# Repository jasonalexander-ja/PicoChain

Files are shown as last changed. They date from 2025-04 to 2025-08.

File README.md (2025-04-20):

# PicoChain

Pico(Daisy)Chain is a simple standard for creating daisy chains of connected devices, allowing I2C and power to be easily distributed out using ethernet patch cables. 

This is a repository containing documentation and reference hardware + software implementations. 

All hardware reference implementations are in KiCAD 8+ format with the PCB layout and Gerbers. 

### Contents: 

- [PicoChainReference](/PicoChainReference); A generic reference design breaking out the power and I2C to pin headers, this can be easily adapted to what ever purpose is desired. 
- [PicoChainZero](/PicoChainZero); A reference design using the Raspberry Pi Zero as a I2C controller, breaks out the Pi Zero's serial to a USB-C connector. 
- [PicoChainTerminator](/PicoChainTerminator); A reference design for a termination endpoint device, one of these needs to be present at the start and end of a chain. 

## Design Overview 

PicoChain uses differential I2C, 12 + 24 volts, all sent down a single RJ45 & twisted pair allowing communication and power for microcontrollers + motors to be supplied using commonly available ethernet patch cables. 

Generation of the differential I2C is handled by the [NXP PCA9615](https://www.nxp.com/docs/en/data-sheet/PCA9615.pdf) meaning that when SCL and SCA is hooked up to this chip, all the same I2C libraries and implementation automatically work with no further modifications. 

The 12 + 24 volts is supplied with the assumption that this will be regulated into the relevant required voltages by the connected devices, the reference implementations regulates a 5V for the microcontroller and a 5V for servo and similar small motors off of the 12V line, and a 12V line is regulated off of the 24V line intended for high power motors. 

Each PicoChain device has 2 RJ45 connectors to send and receive power and data, they don't have a particular direction are all the reference designs have the RJ45s passively connected, tapping off of power and I2C as needed, however, all PicoChain chains need terminators at either end. 

Generally, this is designed for running sequences across some connected devices, with the idea that only 1 large load (I.E. a motor) will be running at a time, reducing the current load going through the patch cables and chained devices. 

### Pinout 

| **RJ45 Pin** | **Function** |
|---|---|
| **1** | GND |
| **2** | +24V |
| **3** | DSDAM |
| **4** | DSCLM |
| **5** | DSCLP |
| **6** | DSDAP |
| **7** | GND |
| **8** | +12V |

Pins 3-6 (inclusive) are generated by the [PCA9615](https://www.nxp.com/docs/en/data-sheet/PCA9615.pdf) and are connected directly to ICs on each device.

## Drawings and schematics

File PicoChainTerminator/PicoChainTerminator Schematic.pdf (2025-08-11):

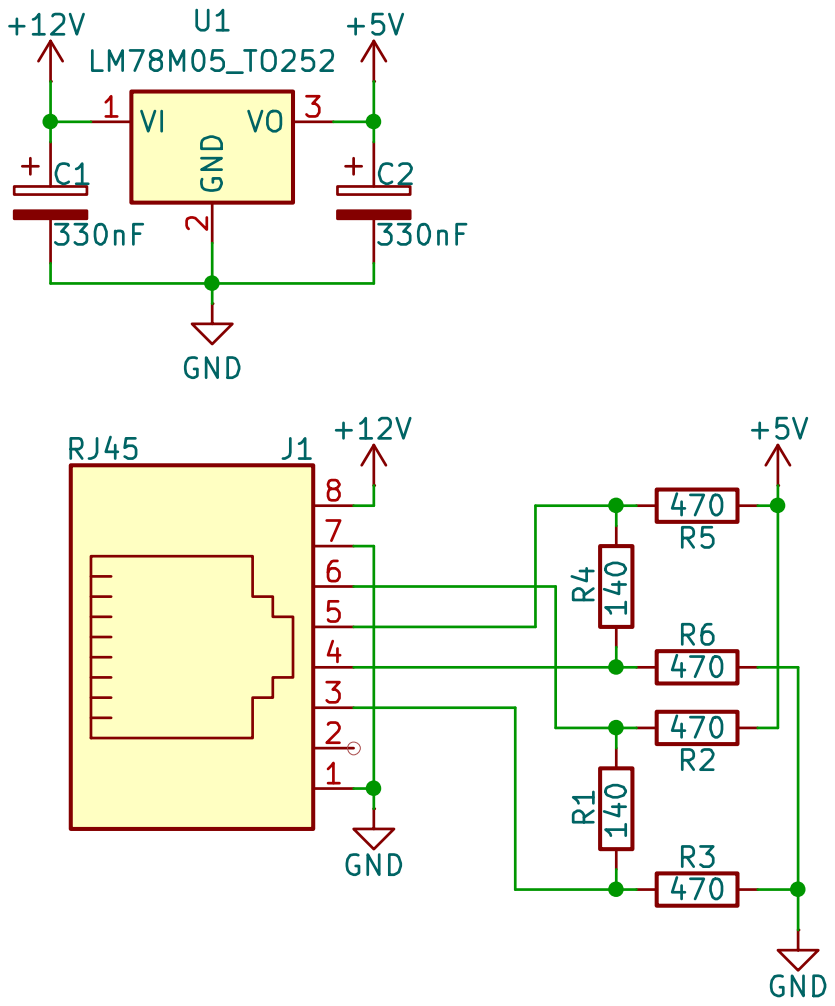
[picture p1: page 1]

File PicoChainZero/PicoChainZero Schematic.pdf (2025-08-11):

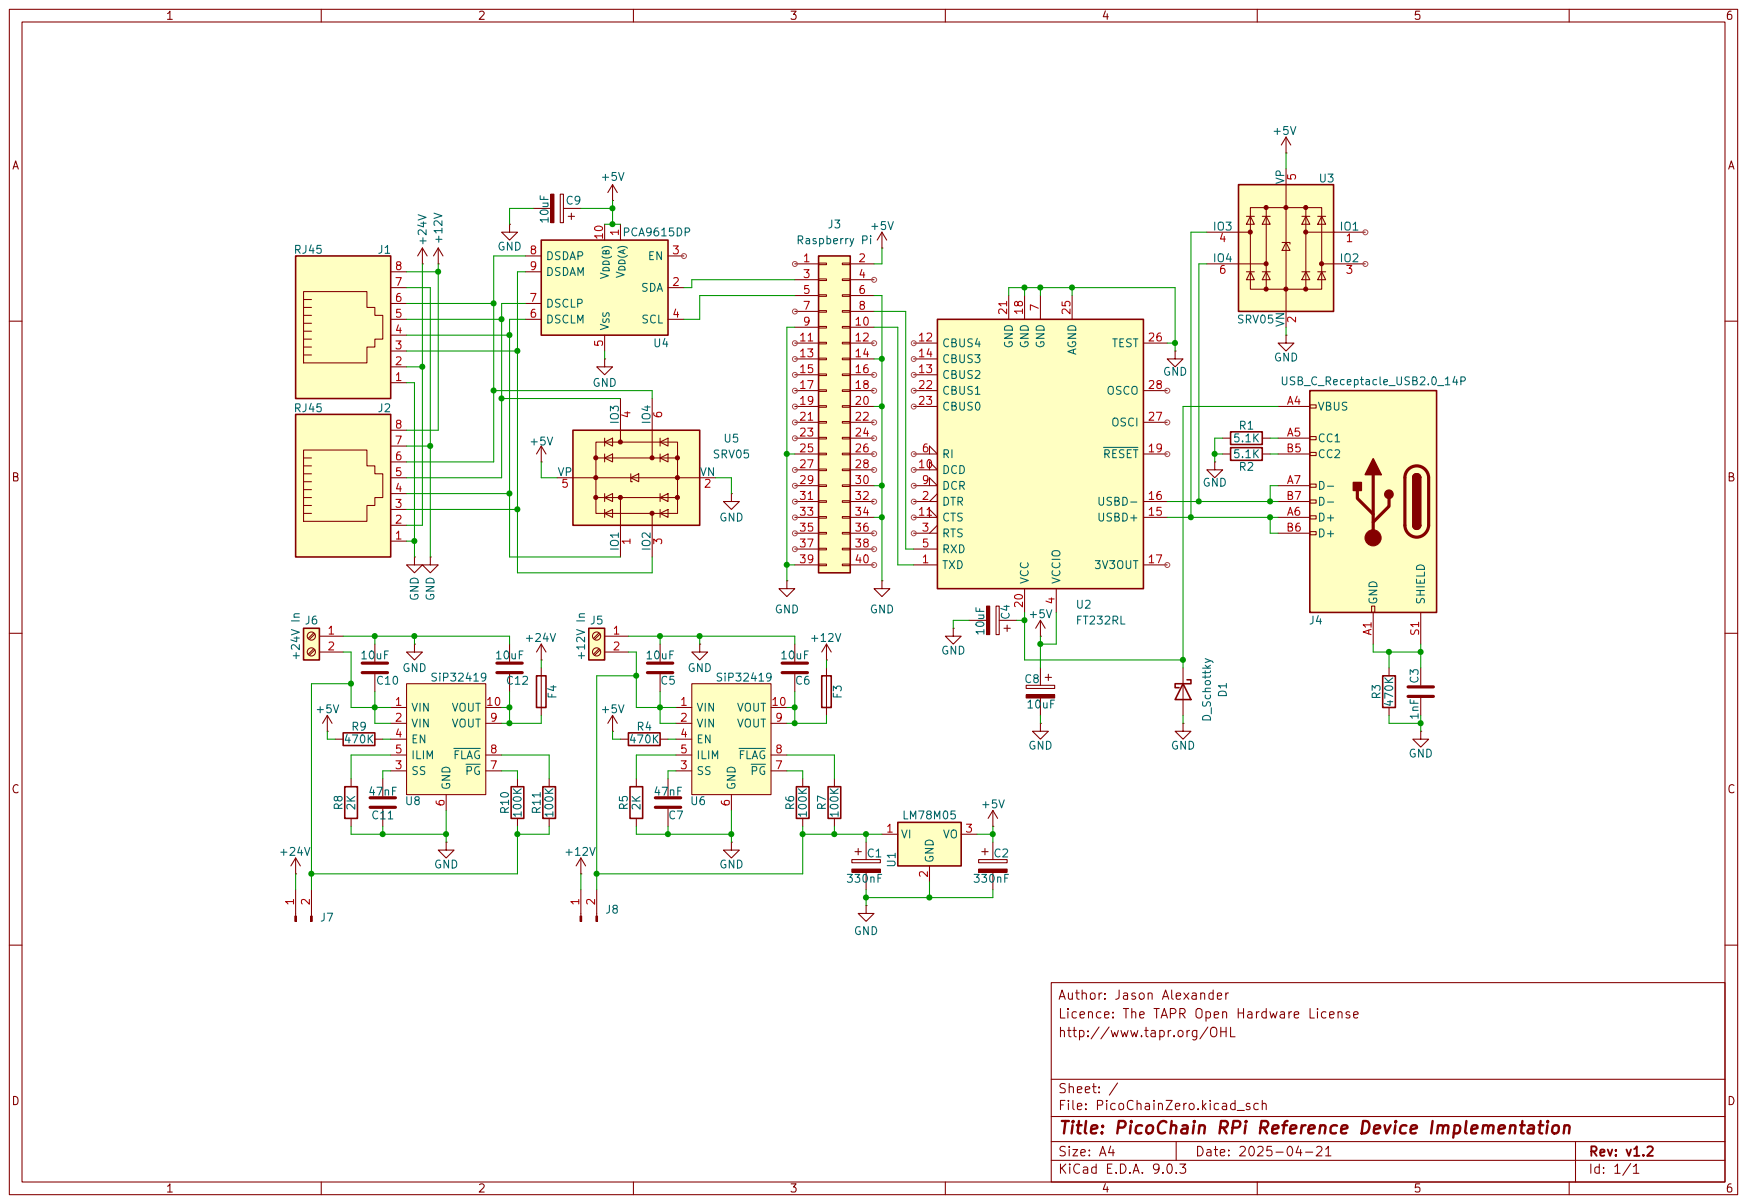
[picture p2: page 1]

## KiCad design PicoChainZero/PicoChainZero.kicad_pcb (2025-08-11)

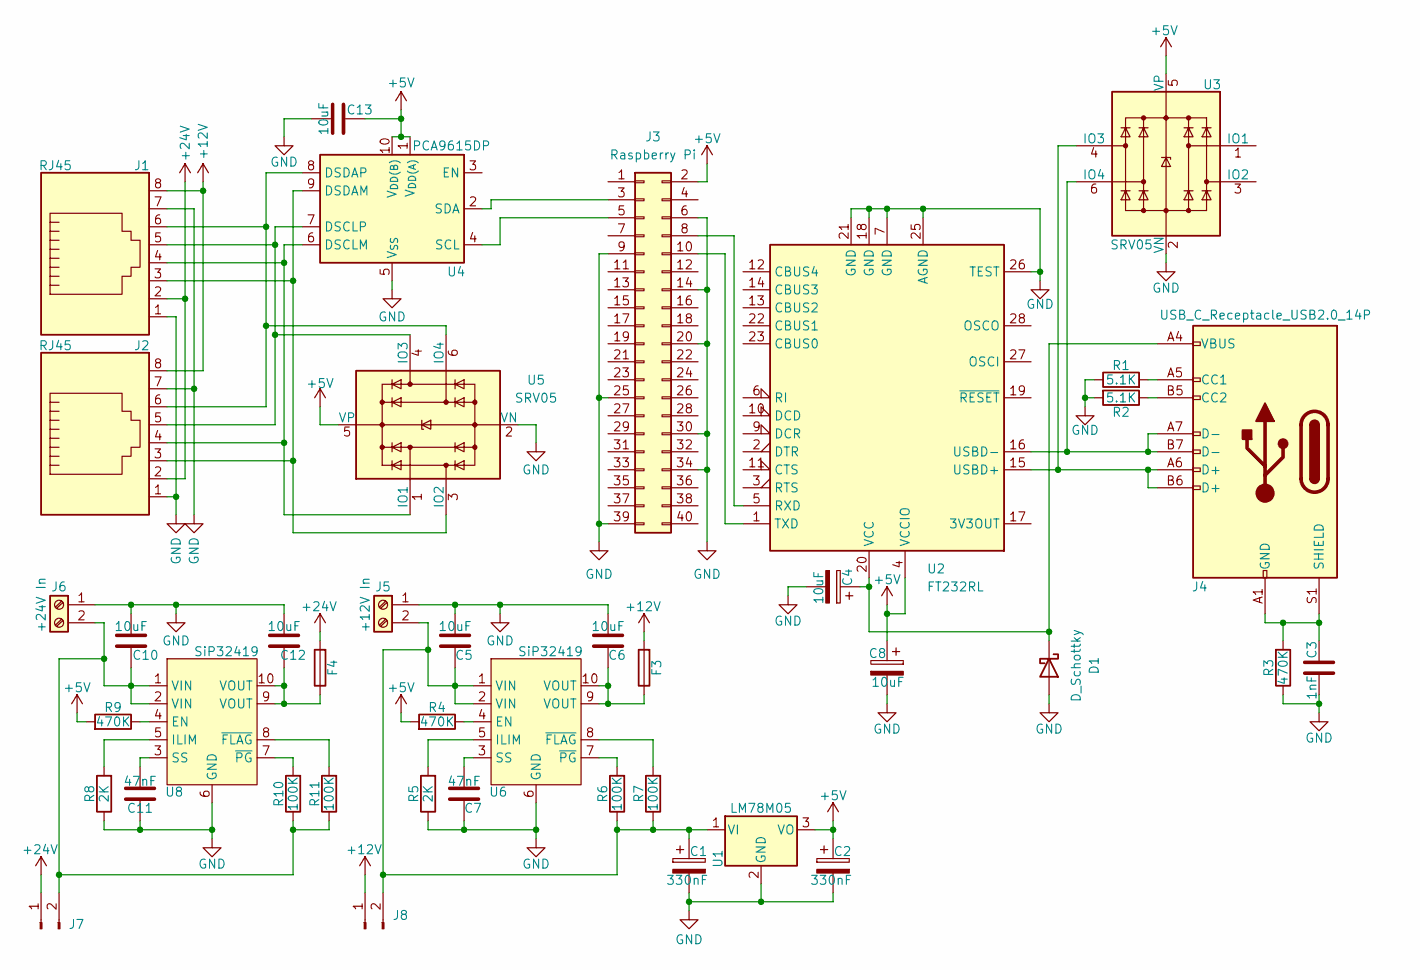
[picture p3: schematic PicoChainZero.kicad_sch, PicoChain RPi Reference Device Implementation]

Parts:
C1, C2: 330nF; CP_EIA-3216-18_Kemet-A
C3: 1nF; C_1206_3216Metric
C4, C8: 10uF; CP_EIA-3216-18_Kemet-A
C5, C6, C10, C12, C13: 10uF; C_0805_2012Metric
C7, C11: 47nF; C_0805_2012Metric
D1: D_Schottky; D_SMA
F3, F4: Fuse; Fuse_0805_2012Metric
J1, J2: RJ45; RJ45_Amphenol_54602-x08_Horizontal
J3: Raspberry Pi; PinHeader_2x20_P2.54mm_Vertical
J4: USB_C_Receptacle_USB2.0_14P; USB_C_Receptacle_GCT_USB4085
J5: +12V In; TerminalBlock_Phoenix_MKDS-1,5-2-5.08_1x02_P5.08mm_Horizont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
J6: +24V In; TerminalBlock_Phoenix_MKDS-1,5-2-5.08_1x02_P5.08mm_Horizont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
J7, J8: Conn_01x02_Pin; PinHeader_1x02_P2.54mm_Vertical
R1, R2: 5.1K; R_0805_2012Metric
R3, R4, R9: 470K; R_0805_2012Metric
R5, R8: 2K; R_0805_2012Metric
R6, R7, R10, R11: 100K; R_0805_2012Metric
U1: LM78M05; TO-252-2
U2: FT232RL; SSOP-28_5.3x10.2mm_P0.65mm
U3, U5: SRV05; SOT-23-6
U4: PCA9615DP; TSSOP-10_3x3mm_P0.5mm
U6, U8: SiP32419; DFN-10-1EP_3x3mm_P0.5mm_EP1.65x2.38mm

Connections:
+5V: C2.1, C8.1, C13.2, J3.2, R4.2, R9.2, U1.3 (VO), U2.4 (VCCIO), U3.5 (VP), U4.1 (V_{DD(A)}), U4.10 (V_{DD(B)}), U5.5 (VP)
+12V: F3.2, J1.8, J2.8, J8.1
+24V: F4.2, J1.2, J2.2, J7.1
GND: C1.2, C2.2, C3.2, C4.2, C5.1, C6.1, C7.2, C8.2, C10.1, C11.2, C12.1, C13.1, D1.2 (A), J1.1, J1.7, J2.1, J2.7, J3.6, J3.9, J3.14, J3.20, J3.25, J3.30, J3.34, J3.39, J5.1, J6.1, R1.1, R2.2, R3.1, R5.1, R8.1, U1.2 (GND), U2.7 (GND), U2.18 (GND), U2.21 (GND), U2.25 (AGND), U2.26 (TEST), U3.2 (VN), U4.5 (V_{SS}), U5.2 (VN), U6.6 (GND), U8.6 (GND)
unnamed: C6.2, F3.1, U6.9 (VOUT), U6.10 (VOUT)
unnamed: C12.2, F4.1, U8.9 (VOUT), U8.10 (VOUT)
unnamed: C4.1, D1.1 (K), J4.A4 (VBUS), J4.A9 (VBUS), J4.B4 (VBUS), J4.B9 (VBUS), U2.20 (VCC)
unnamed: J3.3, U4.2 (SDA)
unnamed: J3.5, U4.4 (SCL)
unnamed: J3.8, U2.5 (RXD)
unnamed: J3.10, U2.1 (TXD)
unnamed: J4.A5 (CC1), R1.2
unnamed: J4.B5 (CC2), R2.1
unnamed: C3.1, J4.A1 (GND), J4.A12 (GND), J4.B1 (GND), J4.B12 (GND), J4.S1 (SHIELD), R3.2
unnamed: C1.1, C5.2, J5.2, J8.2, R6.1, R7.1, U1.1 (VI), U6.1 (VIN), U6.2 (VIN)
unnamed: C10.2, J6.2, J7.2, R10.1, R11.1, U8.1 (VIN), U8.2 (VIN)
unnamed: J4.A6 (D+), J4.B6 (D+), U2.15 (USBD+), U3.4 (IO3)
unnamed: J4.A7 (D-), J4.B7 (D-), U2.16 (USBD-), U3.6 (IO4)
unnamed: J1.4, J2.4, U4.6 (DSCLM), U5.1 (IO1)
unnamed: J1.5, J2.5, U4.7 (DSCLP), U5.4 (IO3)
unnamed: J1.3, J2.3, U4.9 (DSDAM), U5.3 (IO2)
unnamed: J1.6, J2.6, U4.8 (DSDAP), U5.6 (IO4)
unnamed: R4.1, U6.4 (EN)
unnamed: R5.2, U6.5 (ILIM)
unnamed: C7.1, U6.3 (SS)
unnamed: R7.2, U6.8 (~FLAG)
unnamed: R6.2, U6.7 (~PG)
unnamed: R9.1, U8.4 (EN)
unnamed: R8.2, U8.5 (ILIM)
unnamed: C11.1, U8.3 (SS)
unnamed: R11.2, U8.8 (~FLAG)
unnamed: R10.2, U8.7 (~PG)

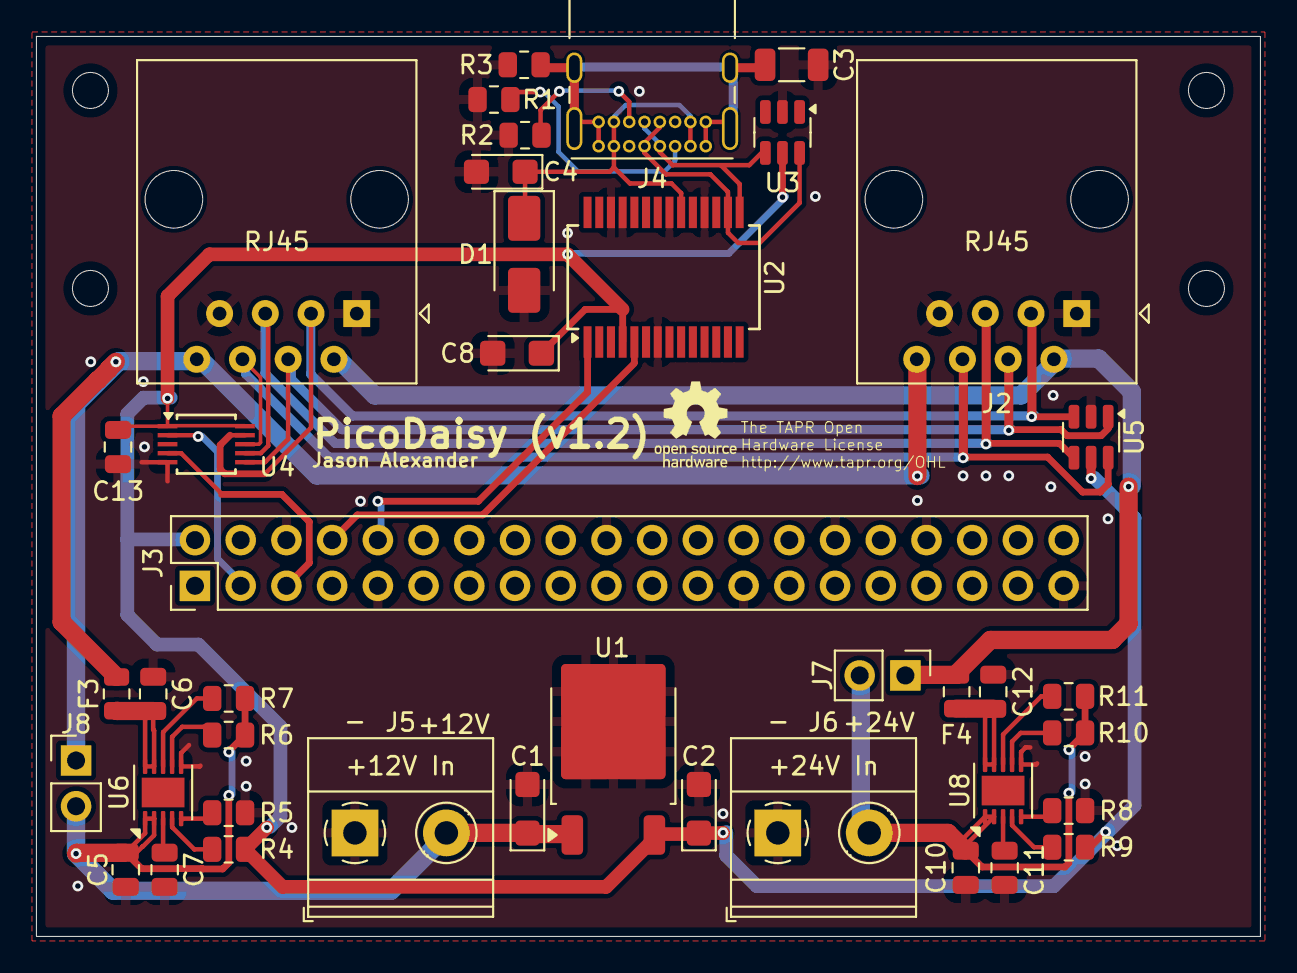
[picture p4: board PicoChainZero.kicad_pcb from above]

Board: 4 copper layers, 68.0 x 50.0 mm, 41 parts (0 on the bottom side), 32 nets.

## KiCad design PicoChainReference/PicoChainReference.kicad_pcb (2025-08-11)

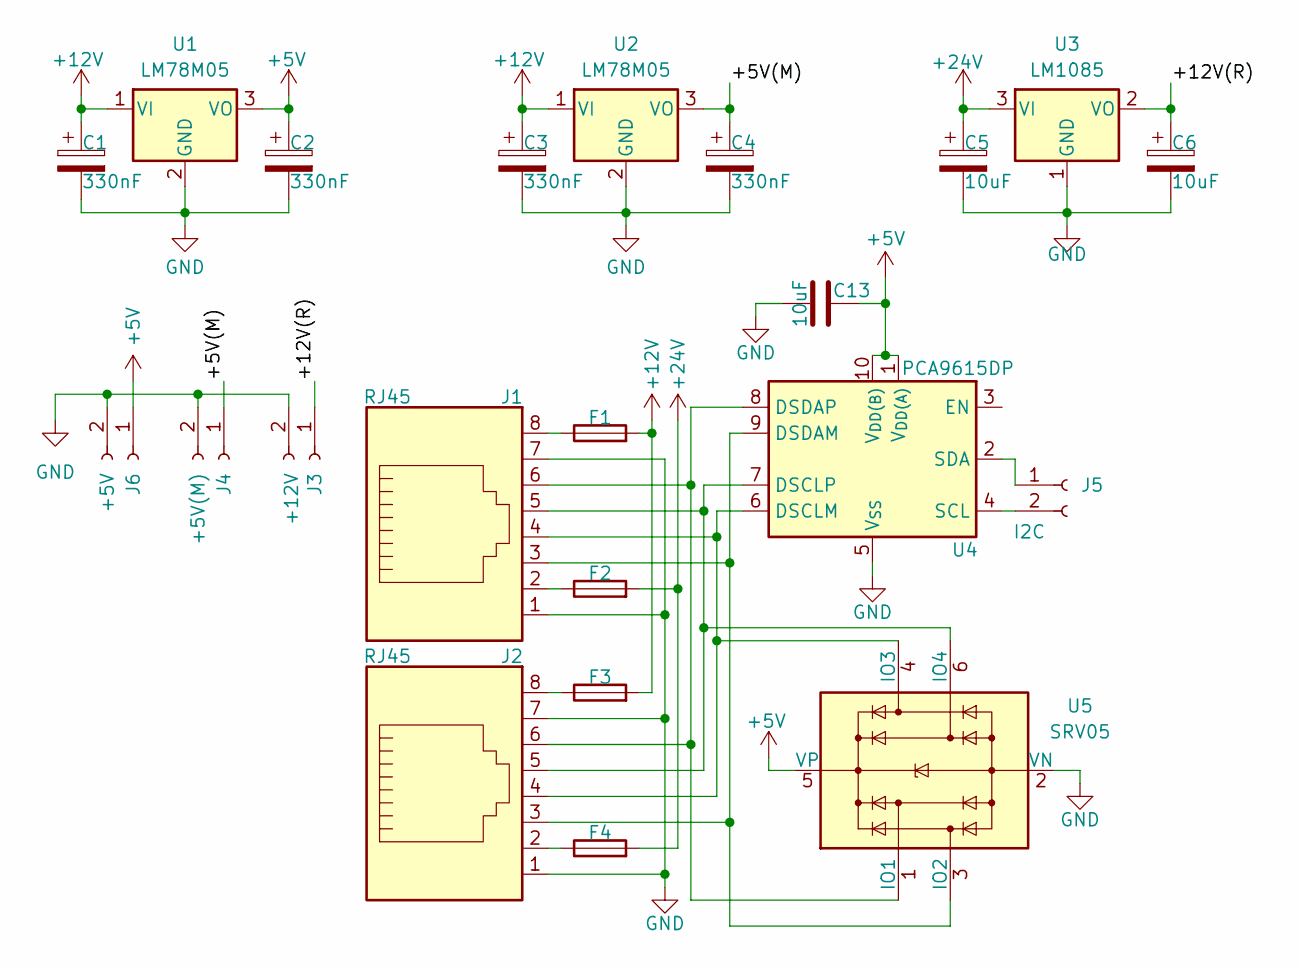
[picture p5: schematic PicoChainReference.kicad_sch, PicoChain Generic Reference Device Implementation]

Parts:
C1, C2, C3, C4: 330nF; CP_EIA-3216-18_Kemet-A
C5, C6: 10uF; CP_EIA-3528-21_Kemet-B
C13: 10uF; C_0805_2012Metric
F1, F2, F3, F4: Fuse; Fuse_0805_2012Metric
J1, J2: RJ45; RJ45_Amphenol_54602-x08_Horizontal
J3: +12V; PinHeader_1x02_P2.54mm_Vertical
J4: +5V(M); PinHeader_1x02_P2.54mm_Vertical
J5: I2C; PinHeader_1x02_P2.54mm_Vertical
J6: +5V; PinHeader_1x02_P2.54mm_Vertical
U1, U2: LM78M05; TO-252-2
U3: LM1085; TO254P1524X483-4N
U4: PCA9615DP; TSSOP-10_3x3mm_P0.5mm
U5: SRV05; SOT-23-6

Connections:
+5V: C2.1, C13.2, J6.1, U1.3 (VO), U4.1 (V_{DD(A)}), U4.10 (V_{DD(B)}), U5.5 (VP)
+12V: C1.1, C3.1, F1.2, F3.2, U1.1 (VI), U2.1 (VI)
+24V: C5.1, F2.2, F4.2, U3.3 (VI)
/+5V(M): C4.1, J4.1, U2.3 (VO)
/+12V(R): C6.1, J3.1, U3.2 (VO)
GND: C1.2, C2.2, C3.2, C4.2, C5.2, C6.2, C13.1, J1.1, J1.7, J2.1, J2.7, J3.2, J4.2, J6.2, U1.2 (GND), U2.2 (GND), U3.1 (GND), U4.5 (V_{SS}), U5.2 (VN)
unnamed: F1.1, J1.8
unnamed: F2.1, J1.2
unnamed: F3.1, J2.8
unnamed: F4.1, J2.2
unnamed: J5.1, U4.2 (SDA)
unnamed: J5.2, U4.4 (SCL)
unnamed: J1.4, J2.4, U4.6 (DSCLM), U5.4 (IO3)
unnamed: J1.5, J2.5, U4.7 (DSCLP), U5.6 (IO4)
unnamed: J1.3, J2.3, U4.9 (DSDAM), U5.3 (IO2)
unnamed: J1.6, J2.6, U4.8 (DSDAP), U5.1 (IO1)

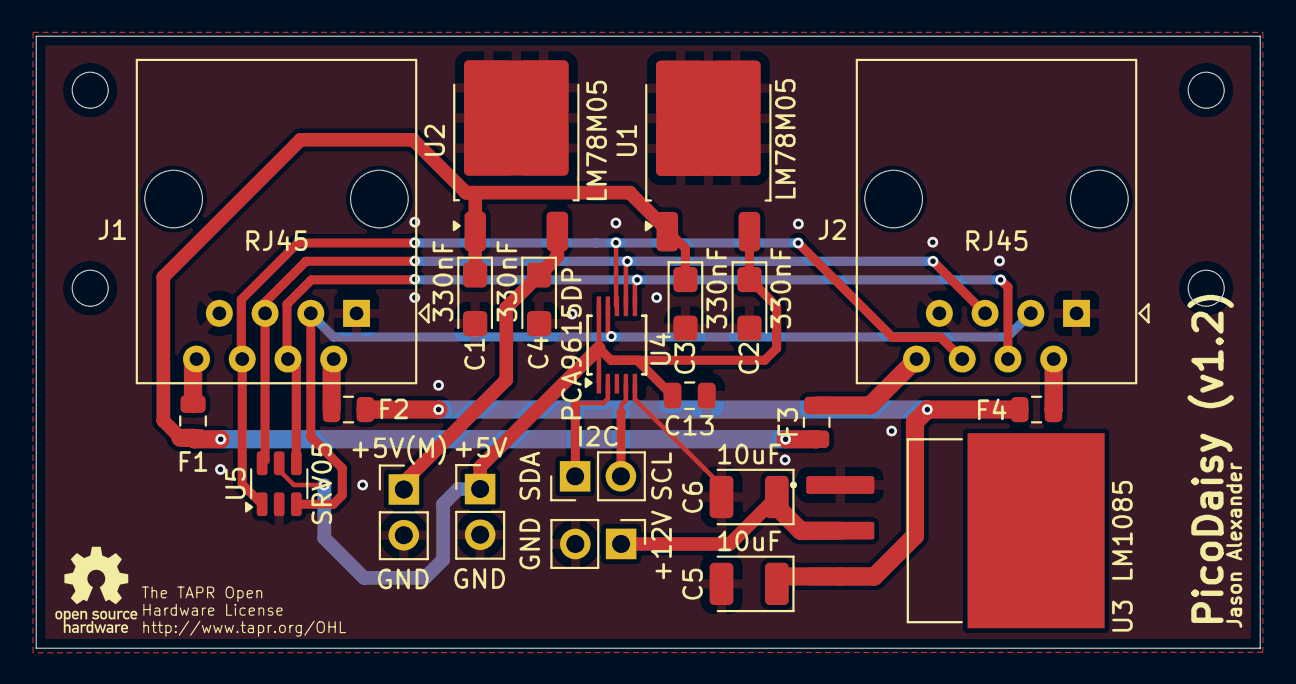
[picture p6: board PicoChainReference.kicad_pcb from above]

Board: 4 copper layers, 68.0 x 34.0 mm, 22 parts (0 on the bottom side), 16 nets.

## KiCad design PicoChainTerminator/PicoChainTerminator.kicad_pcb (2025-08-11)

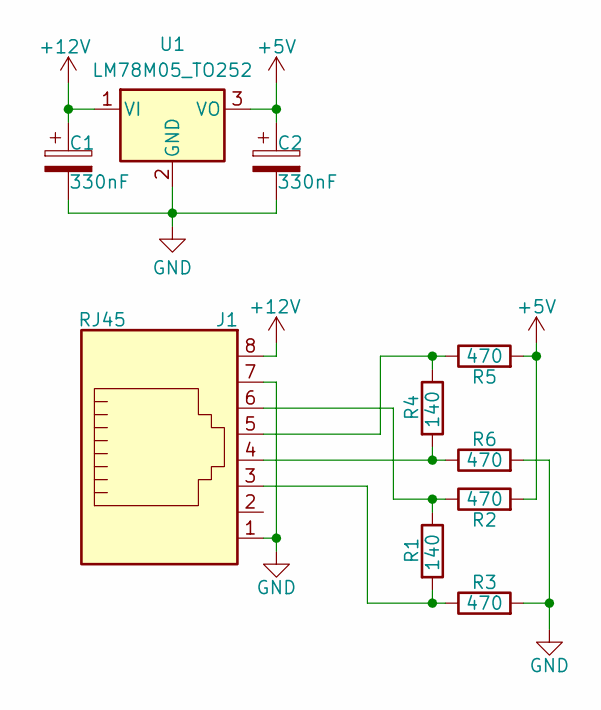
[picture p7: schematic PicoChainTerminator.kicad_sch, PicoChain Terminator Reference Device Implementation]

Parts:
C1, C2: 330nF; CP_EIA-3216-18_Kemet-A
J1: RJ45; RJ45_Amphenol_54602-x08_Horizontal
R1, R4: 140; R_0805_2012Metric
R2, R3, R5, R6: 470; R_0805_2012Metric
U1: LM78M05_TO252; TO-252-2

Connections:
+5V: C2.1, R2.2, R5.2, U1.3 (VO)
+12V: C1.1, J1.8, U1.1 (VI)
GND: C1.2, C2.2, J1.1, J1.7, R3.2, R6.2, U1.2 (GND)
unnamed: J1.3, R1.2, R3.1
unnamed: J1.4, R4.2, R6.1
unnamed: J1.5, R4.1, R5.1
unnamed: J1.6, R1.1, R2.1

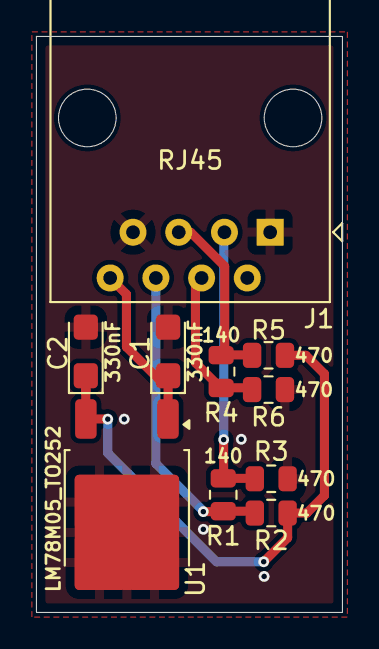
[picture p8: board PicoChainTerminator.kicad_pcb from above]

Board: 4 copper layers, 17.0 x 32.0 mm, 10 parts (0 on the bottom side), 7 nets.

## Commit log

2024-08-12 Initial commit.
    [PicoChain.kicad_pcb, PicoChain.kicad_sch]
2024-08-14 Updated to version 1.1
    [PicoChain-B_Cu.gbl, PicoChain-B_Mask.gbs, PicoChain-B_Silkscreen.gbo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]
2024-08-17 Added reference design
    [PicoChainReference.kicad_pcb, PicoChainReference.kicad_sch]
2024-08-22 Finished off more reference designs and added readme
    [PicoChainATtiny85-B_Cu.gbl, PicoChainATtiny85-B_Mask.gbs, PicoChainATtiny85-B_Silkscreen.gbo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]
2024-08-22 Added licences and PDF schematics
    [PicoChain.kicad_pcb, PicoChain.kicad_sch, PicoChainATtiny85.kicad_pcb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]
2024-08-22 Added open source hardware logo to PCBs
    [PicoChain.kicad_pcb, PicoChainATtiny85.kicad_pcb, PicoChainReference.kicad_pcb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]
2024-08-22 Added terminator reference design
    [PicoChainTerminator.kicad_pcb, PicoChainTerminator.kicad_sch]
2024-08-22 Regenerated gerbers
    [PicoChain-B_Cu.gbl, PicoChain-B_Mask.gbs, PicoChain-B_Silkscreen.gbo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]
2024-08-22 Updated PDF schematic.
2024-08-23 Made pass through power rails larger.
    [PicoChain-B_Cu.gbl, PicoChain-B_Mask.gbs, PicoChain-B_Silkscreen.gbo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]
2025-02-14 Updated PicoChainZero base board.
    [PicoChain.kicad_pcb, PicoChain.kicad_sch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]
2025-02-14 Added PicoChainZero baseboard schematic PDF
2025-02-15 Updated PicoChainZero PCB layout and generated Gerbers.
    [PicoChainZero-B_Cu.gbl, PicoChainZero-B_Mask.gbs, PicoChainZero-B_Paste.gbp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]
2025-02-15 Updated pdf schematic for PicoChainZero.
2025-04-20 Updated to 1.2
    [PicoChain-B_Cu.gbl, PicoChain-B_Mask.gbs, PicoChain-B_Silkscreen.gbo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]
2025-04-21 Added more fuses to reference implementation
    [PicoChainReference-B_Cu.gbl, PicoChainReference-B_Mask.gbs, PicoChainReference-B_Paste.gbp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]
2025-07-12 Updated example reference gerber files to remove extra inner PCB layers
    [PicoChainReference-B_Cu.gbl, PicoChainReference-B_Mask.gbs, PicoChainReference-B_Paste.gbp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]
2025-07-20 Added decoupling capacitors to dI2C drivers (doh)
    [PicoChainReference-B_Cu.gbl, PicoChainReference-B_Mask.gbs, PicoChainReference-B_Paste.gbp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]
2025-07-21 Adjustments to PicoChainZero
    [PicoChainZero-B_Cu.gbl, PicoChainZero-B_Mask.gbs, PicoChainZero-B_Paste.gbp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]
2025-07-21 Adjusted schematics
    [PicoChainReference.kicad_sch, PicoChainTerminator.kicad_sch, PicoChainZero.kicad_sch]
2025-07-23 Finial changes before ordering first boards.
    [PicoChainReference-B_Cu.gbl, PicoChainReference-B_Mask.gbs, PicoChainReference-B_Paste.gbp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]
2025-08-11 Added BOMs
    [PicoChainTerminator.kicad_pcb]

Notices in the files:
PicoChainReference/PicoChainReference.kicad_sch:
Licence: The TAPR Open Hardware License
